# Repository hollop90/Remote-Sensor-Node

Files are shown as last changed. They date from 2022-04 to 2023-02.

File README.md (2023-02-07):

# Remote-Sensor-Node

An ultlra-low-power LoRaWAN sensor node based on the MCCI LMIC Library. This repository contiains the source code, 3D CAD, the electronic schematics and some images of the project.

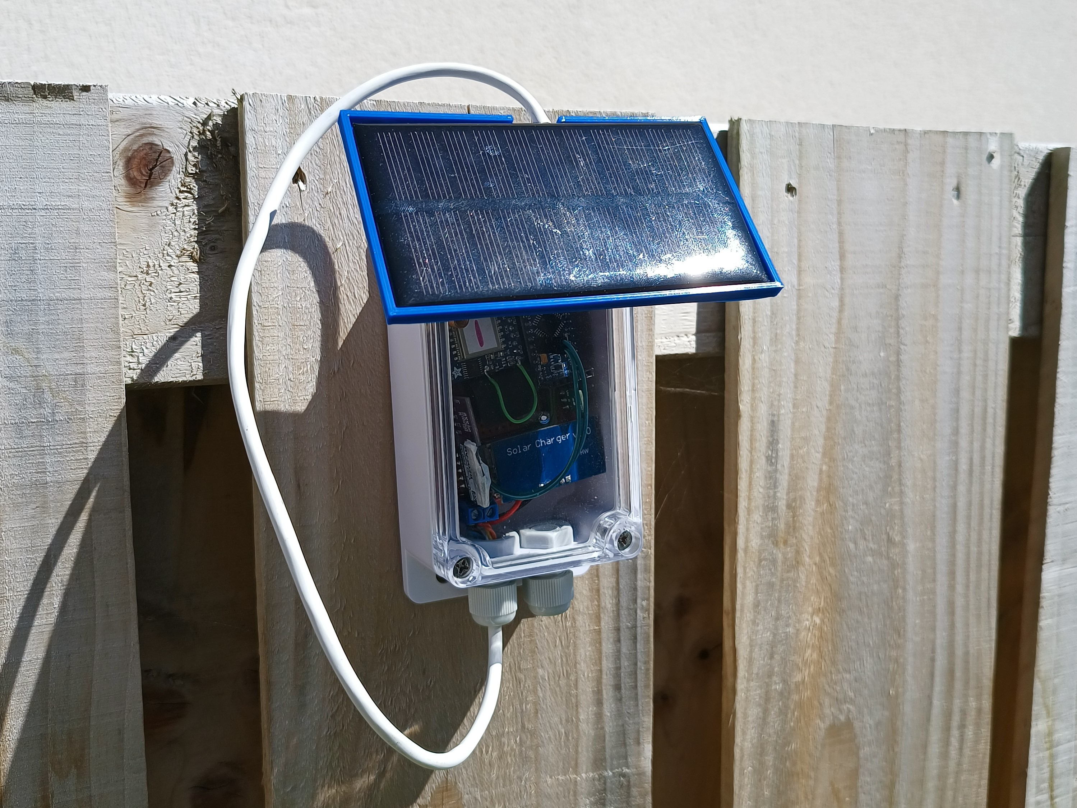
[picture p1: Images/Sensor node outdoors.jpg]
Sensor node outdoors Waterproof case containing an electronic circuit. A solar panel is attatched to the outside of the case


## Features

- Down to 8μA sleep current without SD card holder (4mA with SD card holder)
- 10 minute transmission interval
- 6km range achieved to a public gateway from ground level

Project overview

## Code Setup

The project firmware can be compiled and uploaded using either the Arduino IDE or PlatofrmIO.

**N.B. THE CODE WILL NOT RUN UNLESS A COMPATIBLE RADIO IS HOOKED UP CORRECTLY. SEE [SCHEMATIC](./Design%20Files/Electronics%20Design/schematic.pdf) FOR MORE DETAILS**

### Using Arduino IDE

- Arduino IDE files are located in `sensor_node_arduino`
- Open the file `sensor_node_arduino.ino`
- Install the following libraries. Make sure to install all dependencies when prompted

    ```text
    ClosedCube HDC1080 (By ClosedCube)
    LowPower (By  LowPowerLab)
    MCCI LoRaWAN LMIC library (By Terry Moore)
    RV-3028-C7 (By Macro Yau)
    ```

- Locate your Arduino sketchbook. It's path can be found in the Arduino IDE preferences menu
- Navigate to the LMIC project config folder and edit "lmic_project_config.h" to match the example **Project Config** below

    (Located in `<YOUR_SKETCHBOOK_DIR>/libraries/MCCI_LoRaWAN_LMIC_library/project_config/lmic_project_config.h`)

    More configuration info can by found in the [LMIC library documentation](https://github.com/mcci-catena/arduino-lmic)
- Select Arduino Pro Mini 8MHz from the tools menu and you are ready to upload
- Open the serial monitor and set the baud rate to 115000 bps

### Using PlatformIO (PIO)

Clone this repository and download the VS Code editor if you don't have it already. Next install the PlatformIO extension. Once complete open this repository in VS Code and follow the steps below

- From VS Code open PIO if not already open
- From the Home tab of PIO click "Open Project"
- Select this repository
- Once open, edit this file to match the example **Project Config** below

    (Located in `<WHERE_YOU_CLONED_THIS>/Remote-Sensor-Node/.pio/libdeps/promini/MCCI LoRaWAN LMIC library/project_config/lmic_project_config.h`)
- Libraries should be automatically installed
- On the bottom of the screen hit the arrow pointing right to upload
- Click on the plug icon to open the serial monitor. Follow the instructions to set the baud rate to 115000 bps

#### **Project Config**

```cpp
// project-specific definitions
#define CFG_eu868 1 // Select the right config for your region
#define CFG_sx1276_radio 1 // Select the right config for your radio
#define DISABLE_PING
#define DISABLE_BEACONS
#define DISABLE_JOIN
#define LMIC_DEBUG_LEVEL 0
#define USE_IDEETRON_AES
```

## To Do

- [X] **Properly** archive KiCAD and F360 files
- [ ] Git submodules for PCB libs
- [X] Battery monitoring
- [X] Add STL files for 3D print
- [ ] Make a BOM
- [X] Custom PCB
- [X] Radiation shield for sensors

## Project Blog

[Solar Powered Sensor](https://ugo-uzoukwu.blogspot.com/)

## Development Videos

[YouTube Playlist](https://www.youtube.com/playlist?list=PLkDD2GJCGW-Zxzu5pHdPQPp9Yhqgw_unU)

## Live Data

[Tingspeak](https://thingspeak.com/channels/1655776/)

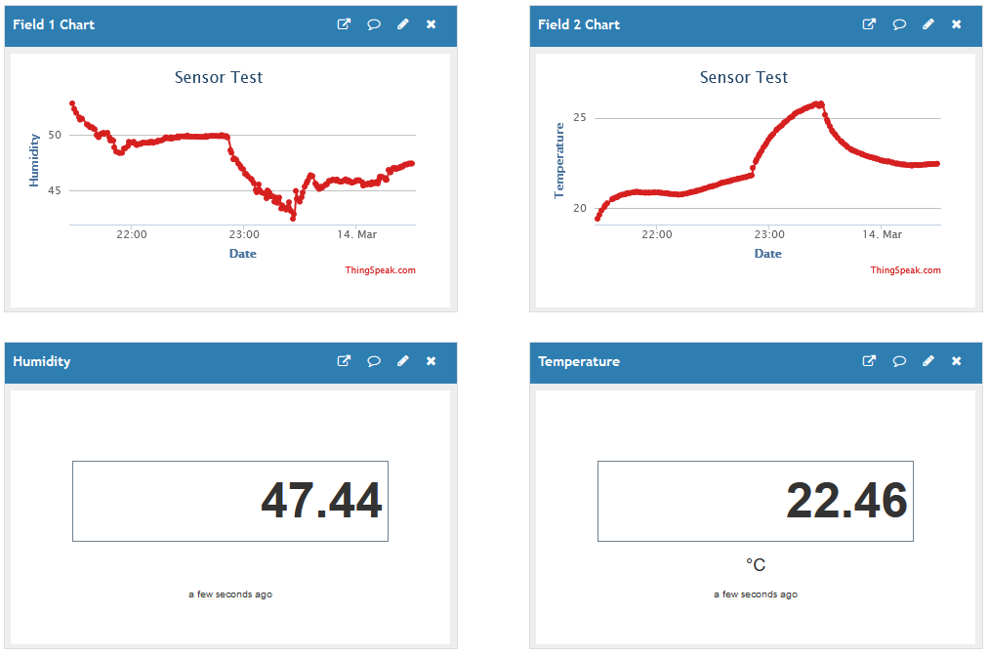
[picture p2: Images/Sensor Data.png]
Sensor Data Two graphs and two digits representing humidity and temperature respectively


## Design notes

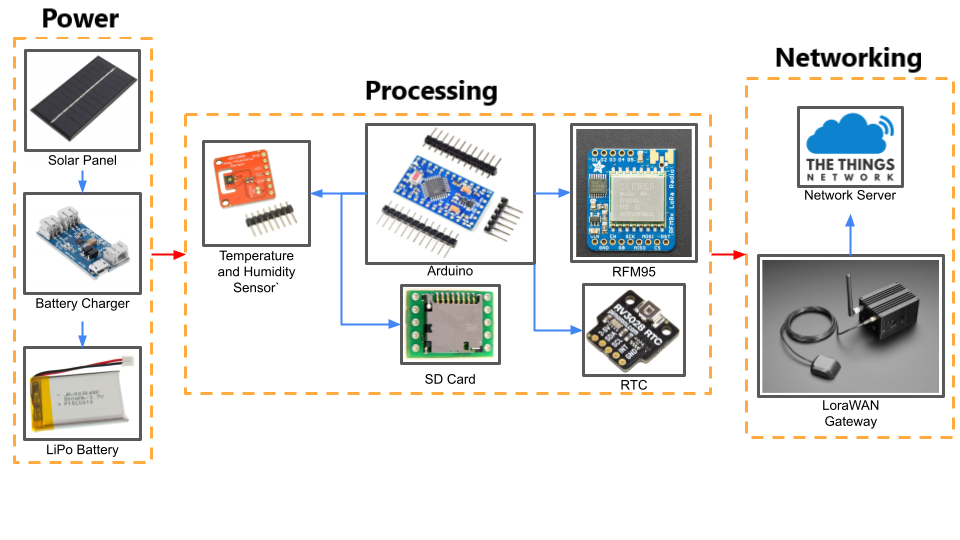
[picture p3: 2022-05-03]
Images/Project Overview 3.png

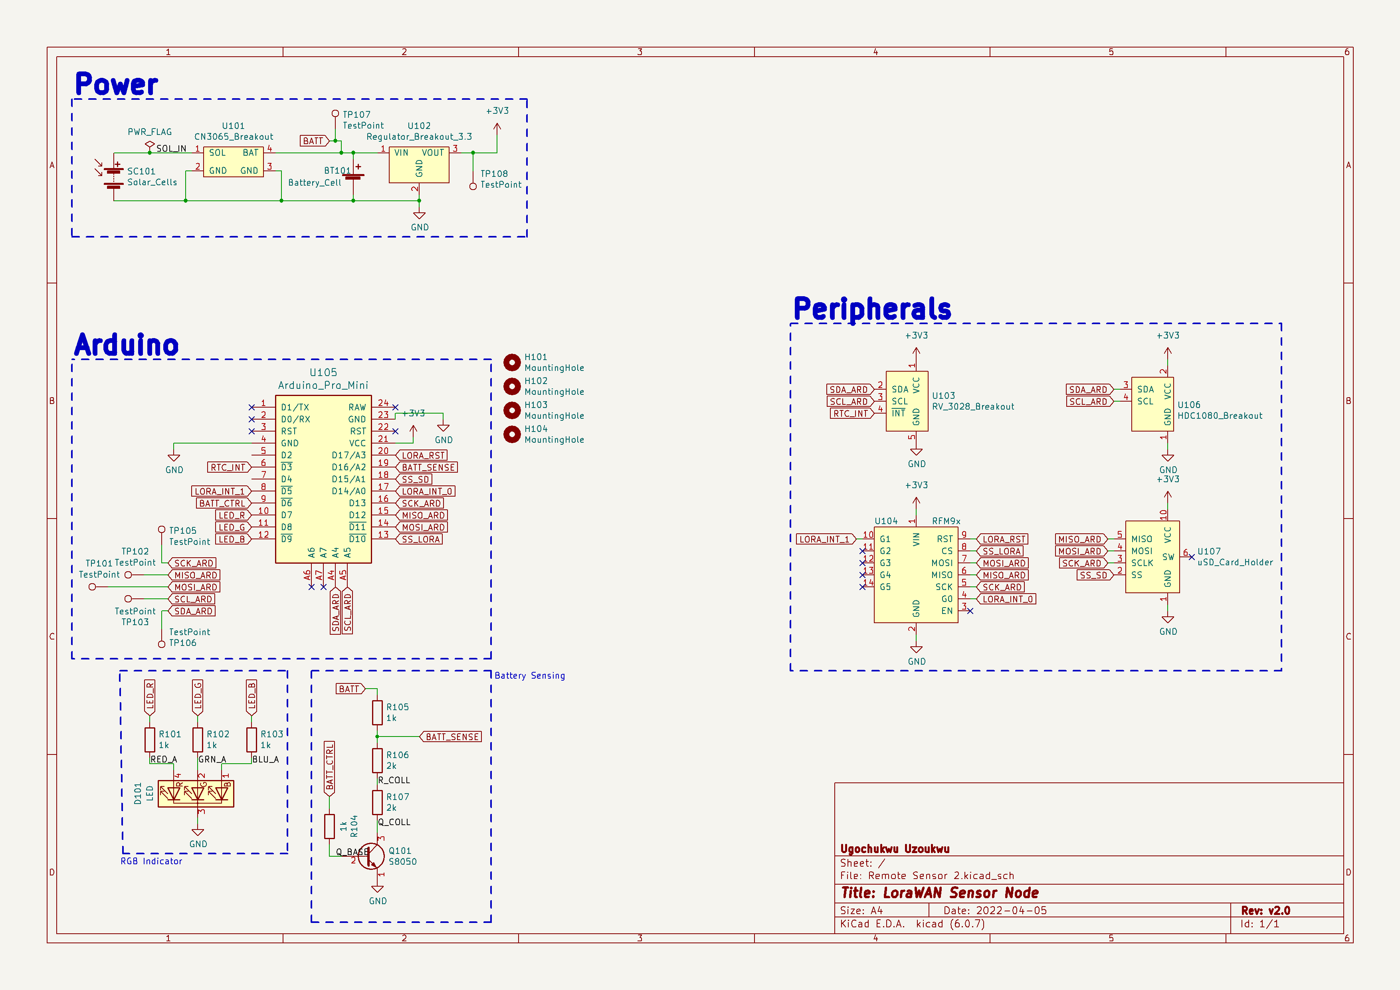
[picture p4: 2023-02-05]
Hardware/pcb/schematic.png

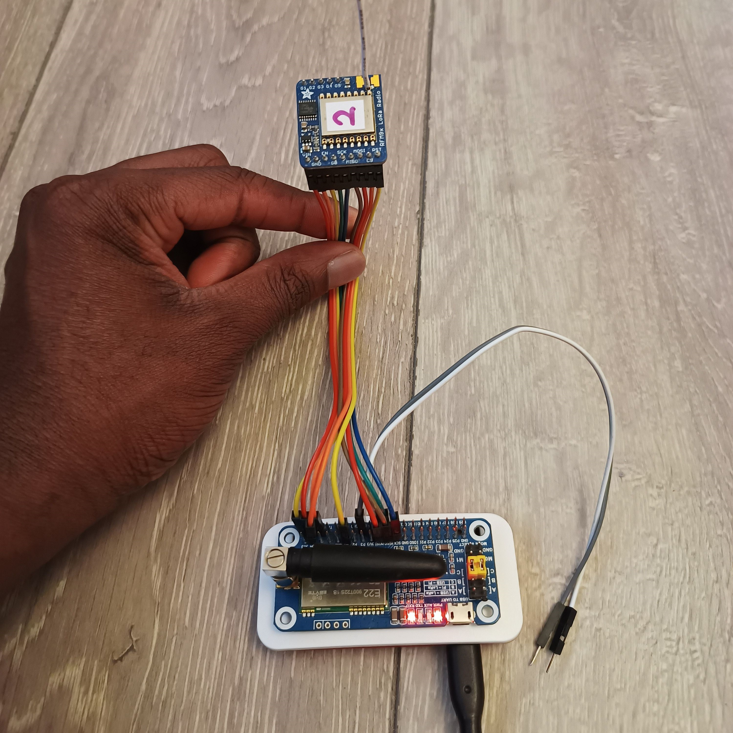
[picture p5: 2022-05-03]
Images/pi zero gateway.jpg

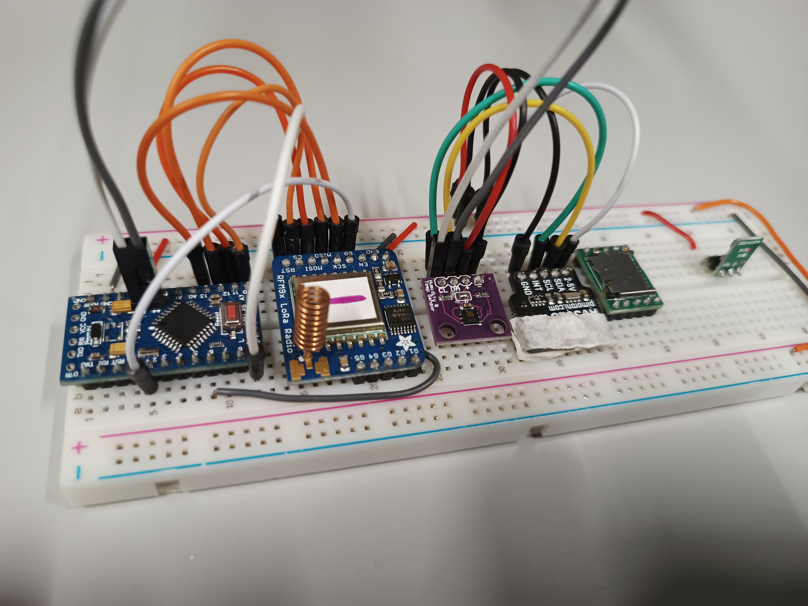
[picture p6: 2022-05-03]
Images/Physical breadboard layout.jpg

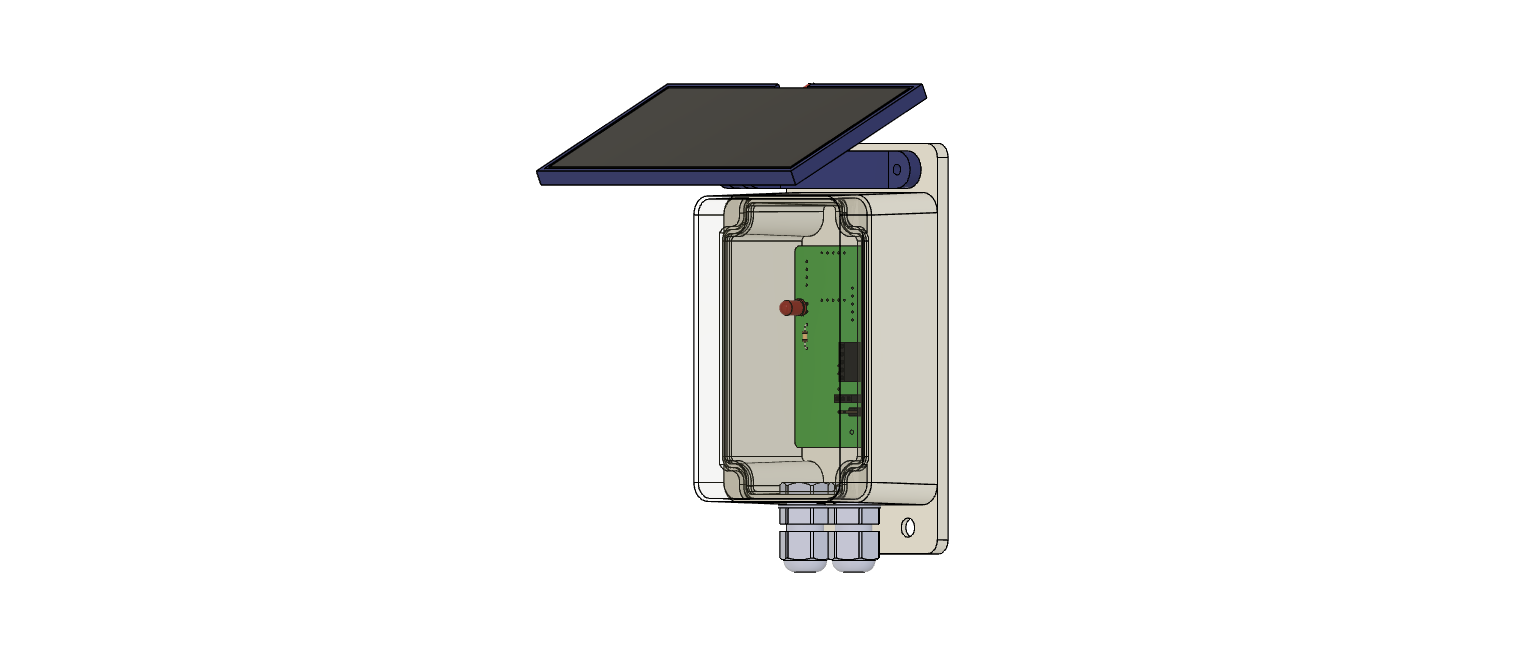
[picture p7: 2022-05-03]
Images/Fusion 360 enclosure.png

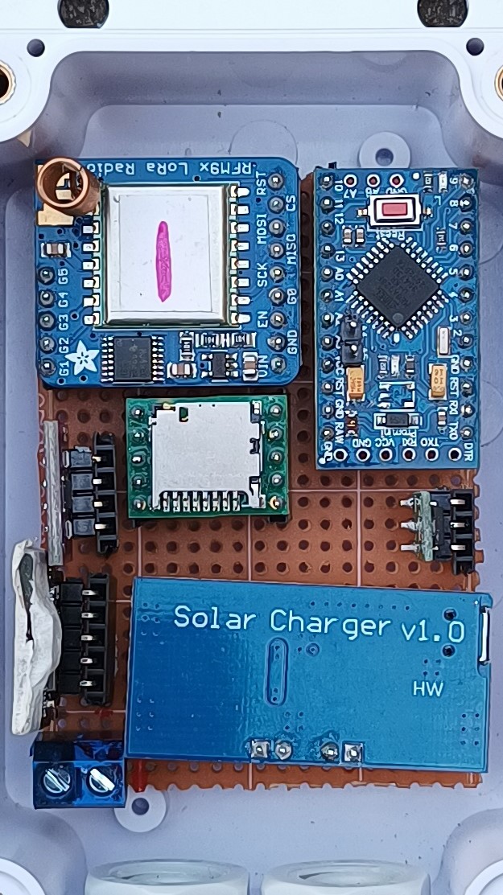
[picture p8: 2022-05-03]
Images/Physical board layout.jpg

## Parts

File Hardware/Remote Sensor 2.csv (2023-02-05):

Source: | C:\Users\nozol\Documents\5School\College Lv7\3rd Yr\SEMESTER 2\PROJ\PCB\Remote Sensor Rev 2\Remote Sensor 2.kicad_sch
Date: | 22/01/2023 17:43:59
Tool: | Eeschema (6.0.7)
Generator: | C:\Program Files\KiCad\6.0\bin\scripting\plugins/bom_csv_grouped_by_value.py
Component Count: | 29
Individual Components:
Item | Qty | Reference(s) | Value | LibPart | Footprint | Datasheet
 |  | BT101 | Battery_Cell | Device:Battery_Cell | Connector_PinHeader_2.54mm:PinHeader_1x02_P2.54mm_Vertical | ~
 |  | D101 | LED | Remote-Sensor-2-rescue:LED_BGCR-Device | LED_THT:LED_D5.0mm-4_RGB_Wide_Pins
 |  | H101 | MountingHole | Mechanical:MountingHole | MountingHole:MountingHole_5.5mm | ~
 |  | H102 | MountingHole | Mechanical:MountingHole | MountingHole:MountingHole_5.5mm | ~
 |  | H103 | MountingHole | Mechanical:MountingHole | MountingHole:MountingHole_5.5mm | ~
 |  | H104 | MountingHole | Mechanical:MountingHole | MountingHole:MountingHole_5.5mm | ~
 |  | Q101 | S8050 | Transistor_BJT:S8050 | Package_TO_SOT_THT:TO-92_Inline | http://www.unisonic.com.tw/datasheet/S8050.pdf
 |  | R101 | 1k | Device:R | Resistor_THT:R_Axial_DIN0207_L6.3mm_D2.5mm_P2.54mm_Vertical | ~
 |  | R102 | 1k | Device:R | Resistor_THT:R_Axial_DIN0207_L6.3mm_D2.5mm_P2.54mm_Vertical | ~
 |  | R103 | 1k | Device:R | Resistor_THT:R_Axial_DIN0207_L6.3mm_D2.5mm_P2.54mm_Vertical | ~
 |  | R104 | 1k | Device:R | Resistor_THT:R_Axial_DIN0207_L6.3mm_D2.5mm_P10.16mm_Horizontal | ~
 |  | R105 | 1k | Device:R | Resistor_THT:R_Axial_DIN0207_L6.3mm_D2.5mm_P10.16mm_Horizontal | ~
 |  | R106 | 2k | Device:R | Resistor_THT:R_Axial_DIN0207_L6.3mm_D2.5mm_P10.16mm_Horizontal | ~
 |  | R107 | 2k | Device:R | Resistor_THT:R_Axial_DIN0207_L6.3mm_D2.5mm_P10.16mm_Horizontal | ~
 |  | SC101 | Solar_Cells | Device:Solar_Cells | Sensor_Footprints:Terminal_Block_bornier-2_P5.08_No_SS | ~
 |  | TP101 | TestPoint | Connector:TestPoint | TestPoint:TestPoint_THTPad_D1.0mm_Drill0.5mm | ~
 |  | TP102 | TestPoint | Connector:TestPoint | TestPoint:TestPoint_THTPad_D1.0mm_Drill0.5mm | ~
 |  | TP103 | TestPoint | Connector:TestPoint | TestPoint:TestPoint_THTPad_D1.0mm_Drill0.5mm | ~
 |  | TP105 | TestPoint | Connector:TestPoint | TestPoint:TestPoint_THTPad_D1.0mm_Drill0.5mm | ~
 |  | TP106 | TestPoint | Connector:TestPoint | TestPoint:TestPoint_THTPad_D1.0mm_Drill0.5mm | ~
 |  | TP107 | TestPoint | Connector:TestPoint | TestPoint:TestPoint_THTPad_D1.0mm_Drill0.5mm | ~
 |  | TP108 | TestPoint | Connector:TestPoint | TestPoint:TestPoint_THTPad_D1.0mm_Drill0.5mm | ~
 |  | U101 | CN3065_Breakout | Sensor-Parts:CN3065_Breakout | Sensor_Footprints:CN3065_Breakout
 |  | U102 | Regulator_Breakout_3.3 | Sensor-Parts:Regulator_Breakout_3.3 | Connector_PinSocket_2.54mm:PinSocket_1x03_P2.54mm_Vertical
 |  | U103 | RV_3028_Breakout | Sensor-Parts:RV_3028_Breakout | Connector_PinSocket_2.54mm:PinSocket_1x05_P2.54mm_Vertical
 |  | U104 | RFM9x | Sensor-Parts:RFM9x | Sensor_Footprints:RF9x_Breakout
 |  | U105 | Arduino_Pro_Mini | Remote-Sensor-2-rescue:Arduino_Pro_Mini-Arduino | Arduino:Arduino_Pro_Mini | https://www.sparkfun.com/products/11113
 |  | U106 | HDC1080_Breakout | Sensor-Parts:HDC1080_Breakout | Connector_PinSocket_2.54mm:PinSocket_1x04_P2.54mm_Vertical
 |  | U107 | uSD_Card_Holder | Sensor-Parts:uSD_Card_Holder | Sensor_Footprints:PJRC_uSD
Collated Components:
Item | Qty | Reference(s) | Value | LibPart | Footprint | Datasheet
1 | 1 | BT101 | Battery_Cell | Device:Battery_Cell | Connector_PinHeader_2.54mm:PinHeader_1x02_P2.54mm_Vertical | ~
2 | 1 | D101 | LED | Remote-Sensor-2-rescue:LED_BGCR-Device | LED_THT:LED_D5.0mm-4_RGB_Wide_Pins
3 | 4 | H101, H102, H103, H104 | MountingHole | Mechanical:MountingHole | MountingHole:MountingHole_5.5mm | ~
4 | 1 | Q101 | S8050 | Transistor_BJT:S8050 | Package_TO_SOT_THT:TO-92_Inline | http://www.unisonic.com.tw/datasheet/S8050.pdf
5 | 3 | R101, R102, R103 | 1k | Device:R | Resistor_THT:R_Axial_DIN0207_L6.3mm_D2.5mm_P2.54mm_Vertical | ~
6 | 2 | R104, R105 | 1k | Device:R | Resistor_THT:R_Axial_DIN0207_L6.3mm_D2.5mm_P10.16mm_Horizontal | ~
7 | 2 | R106, R107 | 2k | Device:R | Resistor_THT:R_Axial_DIN0207_L6.3mm_D2.5mm_P10.16mm_Horizontal | ~
8 | 1 | SC101 | Solar_Cells | Device:Solar_Cells | Sensor_Footprints:Terminal_Block_bornier-2_P5.08_No_SS | ~
9 | 7 | TP101, TP102, TP103, TP105, TP106, TP107, TP108 | TestPoint | Connector:TestPoint | TestPoint:TestPoint_THTPad_D1.0mm_Drill0.5mm | ~
10 | 1 | U101 | CN3065_Breakout | Sensor-Parts:CN3065_Breakout | Sensor_Footprints:CN3065_Breakout
11 | 1 | U102 | Regulator_Breakout_3.3 | Sensor-Parts:Regulator_Breakout_3.3 | Connector_PinSocket_2.54mm:PinSocket_1x03_P2.54mm_Vertical
12 | 1 | U103 | RV_3028_Breakout | Sensor-Parts:RV_3028_Breakout | Connector_PinSocket_2.54mm:PinSocket_1x05_P2.54mm_Vertical
13 | 1 | U104 | RFM9x | Sensor-Parts:RFM9x | Sensor_Footprints:RF9x_Breakout
14 | 1 | U105 | Arduino_Pro_Mini | Remote-Sensor-2-rescue:Arduino_Pro_Mini-Arduino | Arduino:Arduino_Pro_Mini | https://www.sparkfun.com/products/11113
15 | 1 | U106 | HDC1080_Breakout | Sensor-Parts:HDC1080_Breakout | Connector_PinSocket_2.54mm:PinSocket_1x04_P2.54mm_Vertical
16 | 1 | U107 | uSD_Card_Holder | Sensor-Parts:uSD_Card_Holder | Sensor_Footprints:PJRC_uSD

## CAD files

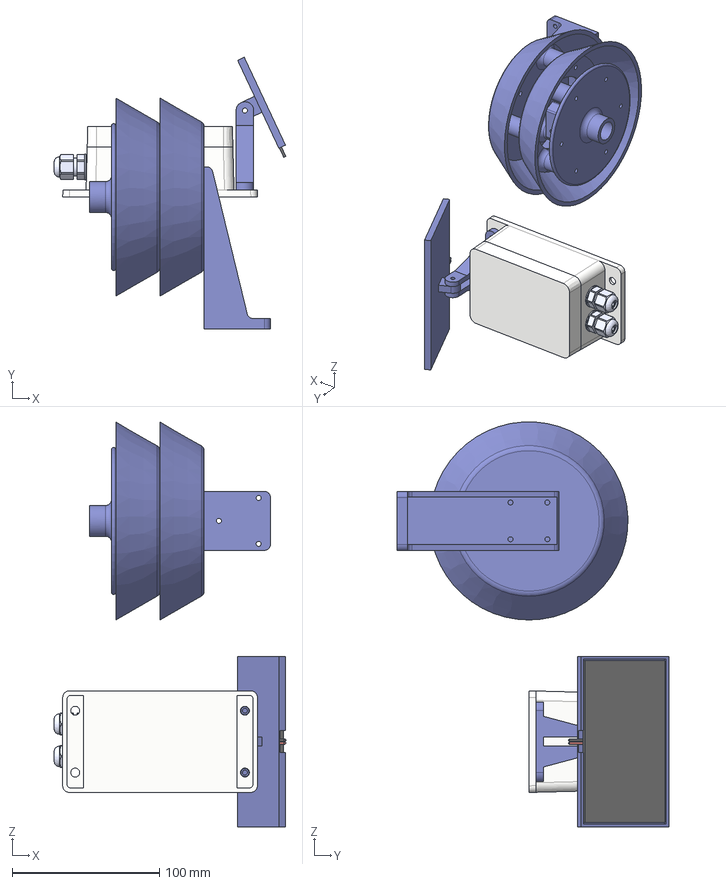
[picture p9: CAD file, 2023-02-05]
Hardware/3D Models/STEP/Enclusure and Radiation Shield.step
157.5 x 184.5 x 275.2 mm
Case
PG7 x 2
Top Cover
1W Panel
CN3065 Breakout
Top Cover (1)
Mid Cover
Cable Guide
Sensor Mount
Wall Bracket

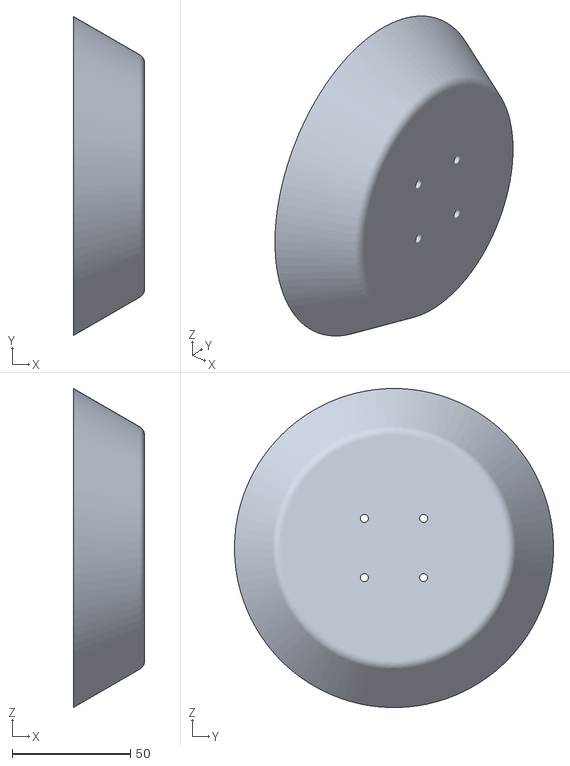
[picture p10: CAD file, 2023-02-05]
Hardware/3D Models/STL/Radiation shield top.stl
30.0 x 134.6 x 134.6

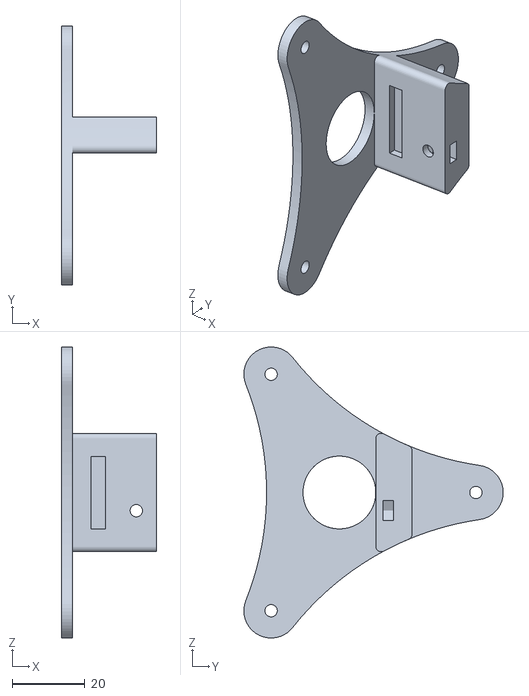
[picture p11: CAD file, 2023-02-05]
Hardware/3D Models/STL/Radiation shield sensor block.stl
26.0 x 71.2 x 79.9

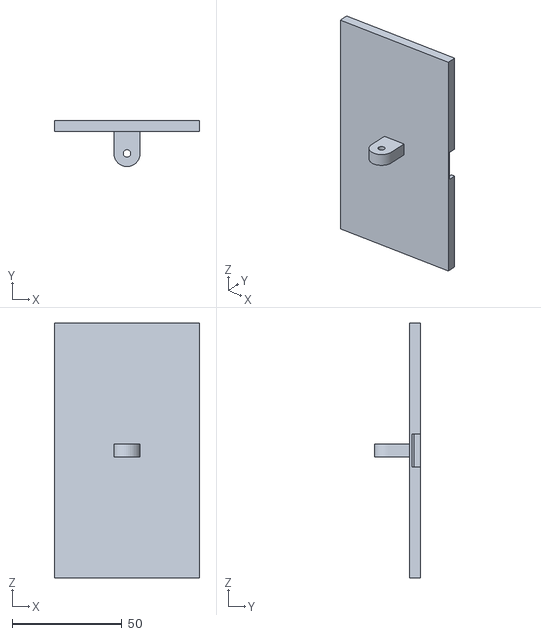
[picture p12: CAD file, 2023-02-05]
Hardware/3D Models/STL/Panel mount flat bed.stl
66.0 x 21.0 x 116.0

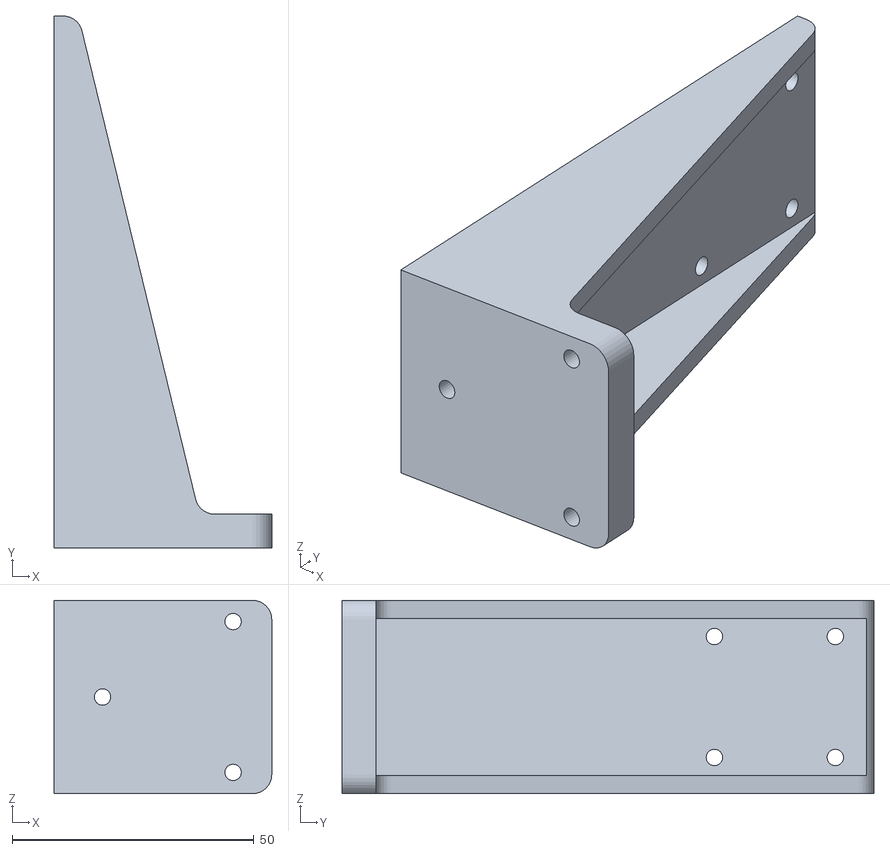
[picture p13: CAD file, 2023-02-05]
Hardware/3D Models/STL/Radiation shield wall bracket.stl
45.0 x 110.0 x 40.0

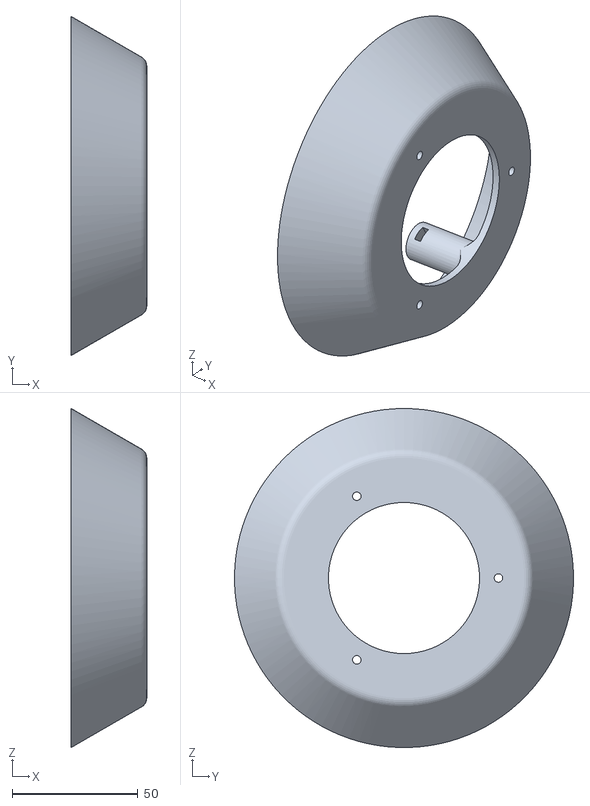
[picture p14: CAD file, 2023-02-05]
Hardware/3D Models/STL/Radiation shield mid.stl
30.0 x 134.6 x 134.6

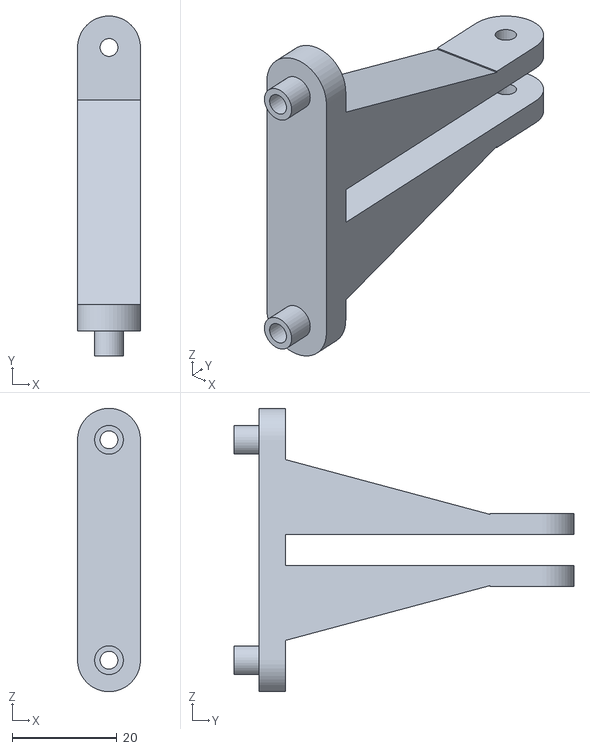
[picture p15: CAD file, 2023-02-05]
Hardware/3D Models/STL/Panel Mount wall bracket.stl
12.0 x 64.8 x 54.0

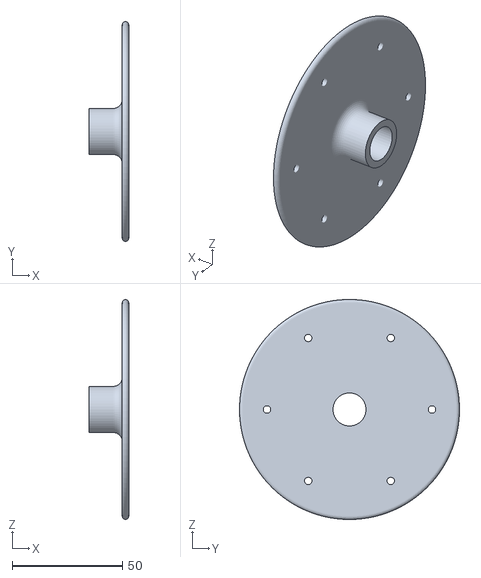
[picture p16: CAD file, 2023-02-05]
Hardware/3D Models/STL/Radiation shield cable guide.stl
18.0 x 100.0 x 100.0

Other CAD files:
Hardware/3D Models/F3Z/Enclusure and Radiation Shield.f3z

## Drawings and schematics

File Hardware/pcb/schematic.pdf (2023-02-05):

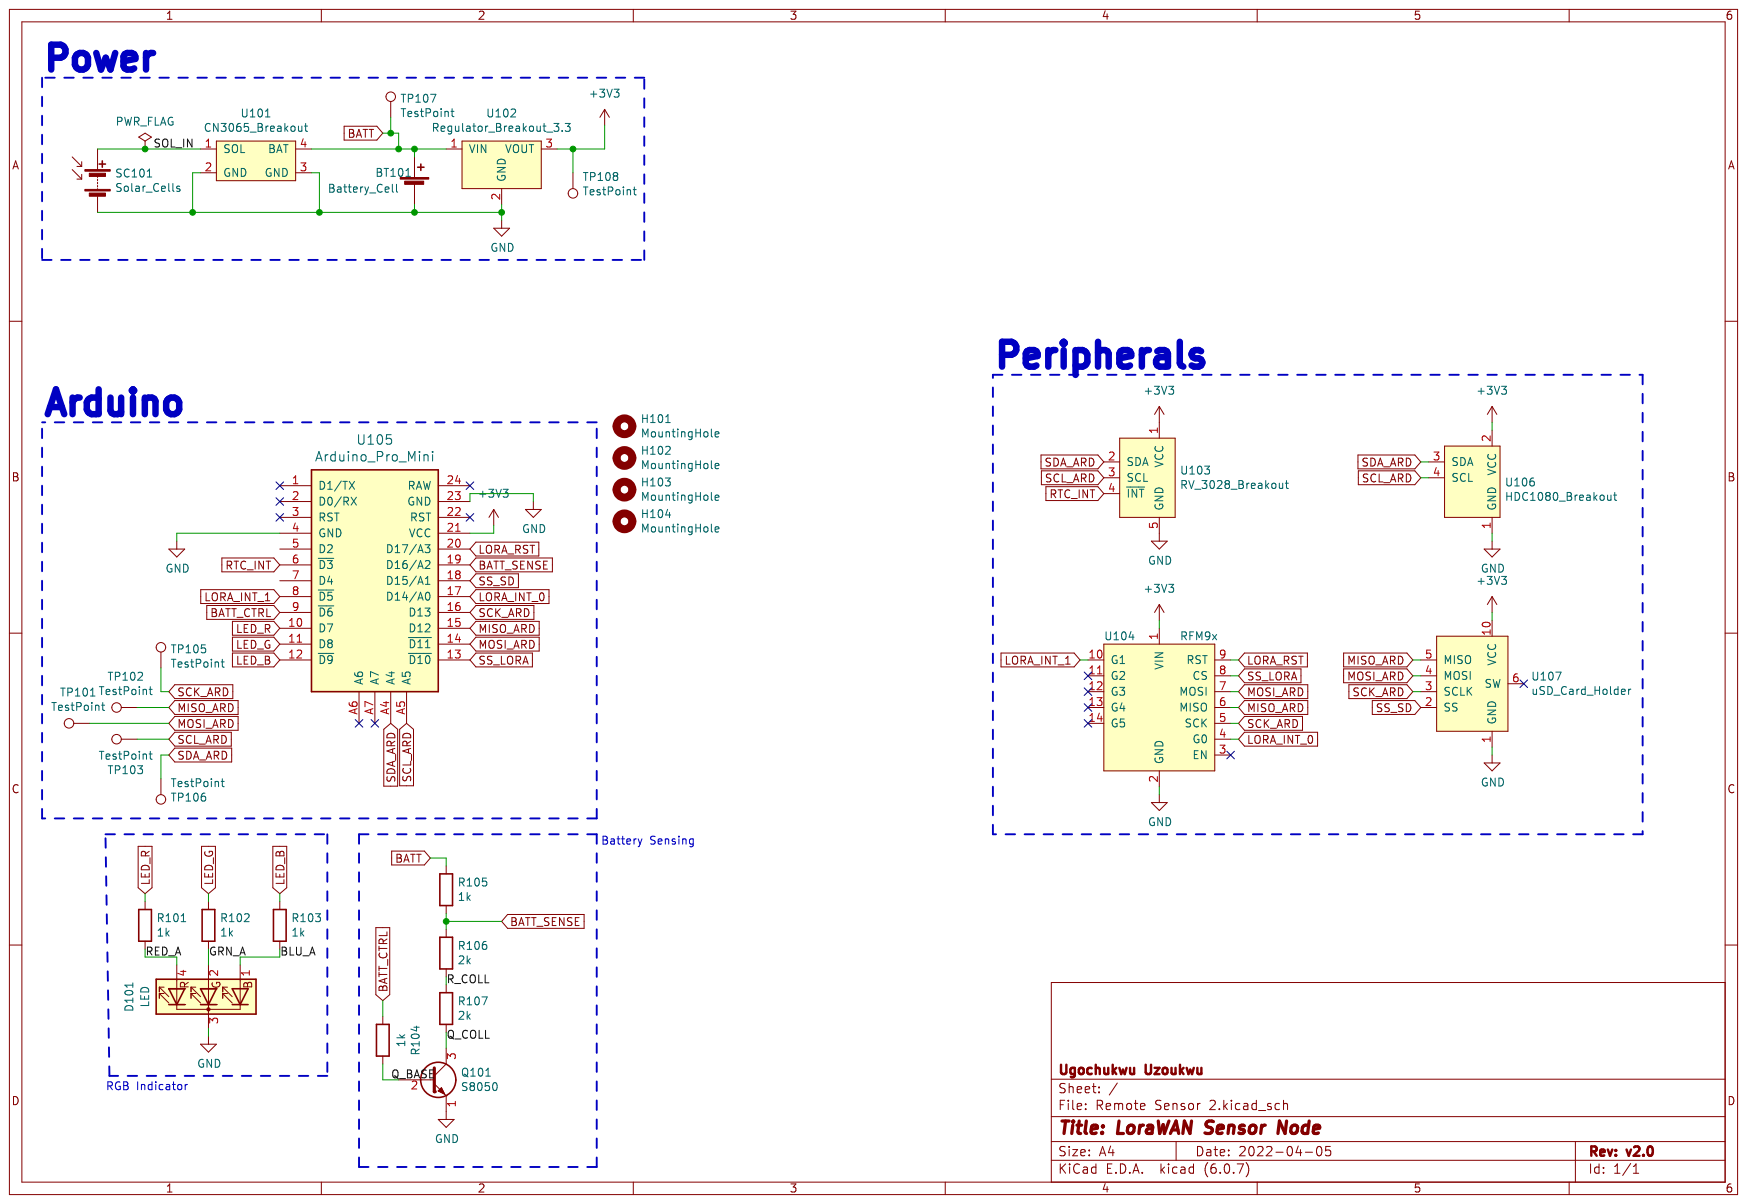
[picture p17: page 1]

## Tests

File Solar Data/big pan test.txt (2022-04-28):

ocv 7.39
scc 345
7.35 3
7.16 7
7.15 8
7.15 9
7.15 11
7.15 14
7.14 17
7.12 23
7.12 35 
7.02 69
6.98 76
6.97 85
6.92 97
6.87 113
6.74 131
6.55 160
6.46 209
5.63 275
3.4 341

charge panel 4.916 batt 3.98 321 ma

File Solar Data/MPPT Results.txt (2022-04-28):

Current (mA)	Voltage (V)	Power (mW)	Resistance (? Ohms)
93	0	0	0.01
86	4.3	369.8	50
60	6	360	110
30	6.3	189	220
0	6.74	0	10000000

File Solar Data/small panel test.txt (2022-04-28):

ocv 6.35
scc 106

6.45 6
6.4 8
6.38 9
6.36 10
6.34 12
6.32 15
6.28 21
6.2 31
6.17 34
6.16 36
6.14 38
6.12 40
6.1 43
6.07 46
6.04 50
6.0 54
5.95 59
5.8 71
5.676 80
5.475 89
5.07 100
4.3 105
3.3 106
2.2 106
1.16 106

charge panel 4.77 batt 3.9 94ma

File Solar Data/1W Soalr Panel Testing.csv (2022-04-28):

1 Watt Panel
Voltage (V) | Current (mA) | Power (mW)
6.35 | 0 | 0
6.45 | 6 | 38.7
6.4 | 8 | 51.2
6.38 | 9 | 57.42
6.36 | 10 | 63.6
6.34 | 12 | 76.08
6.32 | 15 | 94.8
6.28 | 21 | 131.88
6.2 | 31 | 192.2
6.17 | 34 | 209.78
6.16 | 36 | 221.76
6.14 | 38 | 233.32
6.12 | 40 | 244.8
6.1 | 43 | 262.3
6.07 | 46 | 279.22
6.04 | 50 | 302
6 | 54 | 324
5.95 | 59 | 351.05
5.8 | 71 | 411.8
5.676 | 80 | 454.08
5.475 | 89 | 487.275
5.07 | 100 | 507
4.3 | 105 | 451.5
3.3 | 106 | 349.8
2.2 | 106 | 233.2
1.16 | 106 | 122.96
0 | 106 | 0

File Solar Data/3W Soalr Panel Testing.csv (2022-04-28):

3 Watt Panel
Voltage (V) | Current (mA) | Power (mW)
7.39 | 0 | 0
7.35 | 3 | 22.05
7.16 | 7 | 50.12
7.15 | 8 | 57.2
7.15 | 9 | 64.35
7.15 | 11 | 78.65
7.15 | 14 | 100.1
7.14 | 17 | 121.38
7.12 | 23 | 163.76
7.12 | 35 | 249.2
7.02 | 69 | 484.38
6.98 | 76 | 530.48
6.97 | 85 | 592.45
6.92 | 97 | 671.24
6.87 | 113 | 776.31
6.74 | 131 | 882.94
6.55 | 160 | 1048
6.46 | 209 | 1350.14
5.63 | 275 | 1548.25
3.4 | 341 | 1159.4
0 | 345 | 0

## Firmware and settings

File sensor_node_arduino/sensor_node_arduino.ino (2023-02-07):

/**
 * @file main.cpp
 * @author Ugochukwu Uzoukwu
 * @brief A LoRaWAN temperature and humidity sensor node. My final year project
 * @version 1.0
 * @date 2023-02-06
 * 
 * @copyright Copyright (c) 2023
 * 
 */

#include <Arduino.h>
#include <lmic.h>
#include <hal/hal.h>
#include "SensorNodeDefs.h"
#include "lmicJobs.h"

// LoRaWAN NwkSKey, MSB first
static const u1_t NWKSKEY[16] = {};

// LoRaWAN AppSKey, MSB first
static const u1_t APPSKEY[16] = {};

// LoRaWAN end-device address MSB first
static const u4_t DEVADDR = 0x0 ; // <-- Change this address for every node!

// Pin mapping
const lmic_pinmap lmic_pins = {
    .nss = LORA_SS,
    .rxtx = LMIC_UNUSED_PIN,
    .rst = LORA_RST,
    .dio = {LORA_PIN0, LORA_PIN1, LMIC_UNUSED_PIN},
};

void setup() {
    CLKPR = 0x80; // (1000 0000) enable change in clock frequency
    CLKPR = 0x01; // (0000 0001) use clock division factor 2 to reduce the frequency from 16 MHz to 8 MHz
    delay(100);     // per sample code on RF_95 test

    Serial.begin(115200);
    Serial.println(F("Starting Sensor Node"));
    pinMode(LED_G, OUTPUT);
    pinMode(BATT_CTRL, OUTPUT);

    // LMIC init
    os_init();
    // Reset the MAC state. Session and pending data transfers will be discarded.
    LMIC_reset();

    // Set static session parameters. Instead of dynamically establishing a session
    // by joining the network, precomputed session parameters are be provided.
    LMIC_setSession (0x13, DEVADDR, NWKSKEY, APPSKEY);
    setupChannelsEU868();

    // Disable link check validation
    LMIC_setLinkCheckMode(0);

    // TTN uses SF9 for its RX2 window.
    LMIC.dn2Dr = DR_SF9;

    // Set data rate and transmit power for uplink
    LMIC_setDrTxpow(DR_SF7,20);
    
    // Program flow starts here. Defined in **TBD**
    initFunc(&initJob);
}

void loop() {
    os_runloop_once();
}

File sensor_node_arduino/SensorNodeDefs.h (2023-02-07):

/**
 * @file SensorNodeDefs.h
 * @author Ugochukwu Uzoukwu
 * @brief Common definitions accross the projct
 * @version 1.0
 * @date 2023-02-06
 * 
 * @copyright Copyright (c) 2023
 * 
 */

#ifndef UGO_NODE_DEF
#define UGO_NODE_DEF

// Pin definitions
#define LORA_SS     10
#define LORA_RST    17
#define LORA_PIN0   14
#define LORA_PIN1   5

#define LED_R       7
#define LED_G       8
#define LED_B       9

#define BATT_SENSE  16
#define BATT_CTRL   6

#define RTC_INT     3

// Other
#define WAKE_INTERVAL   600  // Unit: Seconds

//! Uncommonet to transmit on only 868.1 MHz THIS VIOLATES LORAWAN/TTN REGULATIONS
#define INDOOR_TESTING

#endif // UGO_NODE_DEF

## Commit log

2022-01-27 Currently implementing the RFM95 example
2022-03-13 Implementing Program Flow
2022-03-14 Loop runs too fast
    [main.cpp]
2022-04-28 Added Project resources
    [1W Soalr Panel Testing.csv, 3W Soalr Panel Testing.csv, BOM.xlsx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]
2022-10-14 doc: Added setup section to README.md
    Currently in the porcess of making the README more useful to
    people who actually want to repoduce the porject.
    This primarily means adding more detailed and up to date information
2022-10-18 repo: Begin to re-organise firmware and hardware
    [Enclusure v13.f3z, Enclusure v14.step]
2023-01-22 major: New features and moved files
    Added a battery voltage reading function
    Moved functions out of main.cpp to their own library (kinda messy)
    Added Hardware files for different types of 3D models
    Added preliminary BOM
    Updated schematic
    [BOM.xlsx, Enclusure and Radiation Shield.f3z, Enclusure and Radiation Shield.step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]
2023-02-07 chore(sensor_node_arduino): New folder for arduino code. Update README.md
    Copied code into a separte folder for arduino IDE users and updated
    README.md to reflect this change
